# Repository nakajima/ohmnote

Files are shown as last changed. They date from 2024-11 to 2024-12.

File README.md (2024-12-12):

# ohmnote

A little ohmmeter.

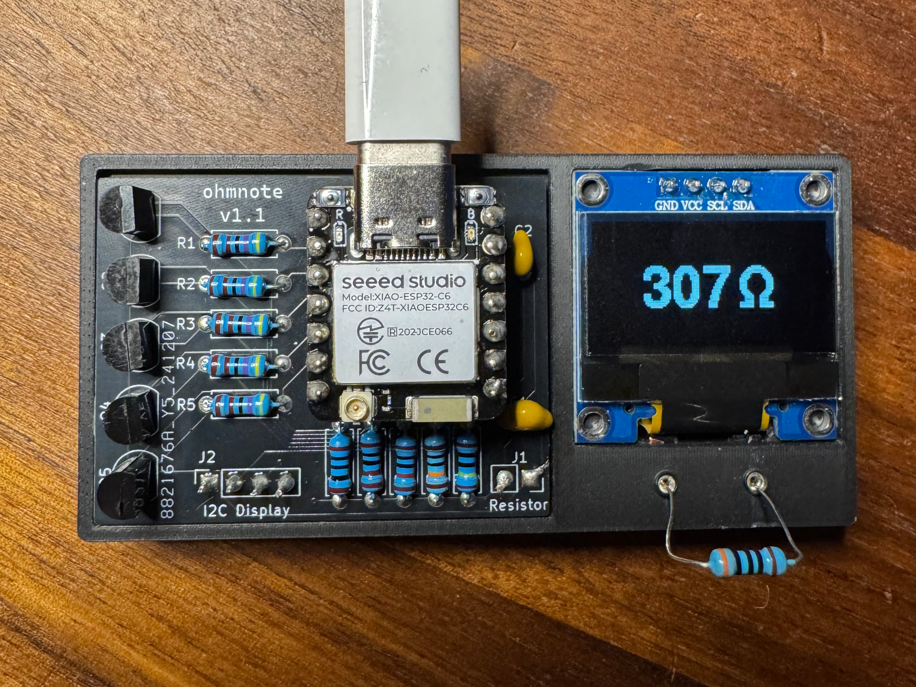
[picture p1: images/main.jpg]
Photo of ohmmeter


I wrote it in rust but it was adapted from: https://simple-circuit.com/arduino-auto-ranging-ohmmeter-lcd and https://www.hackster.io/Costalegre/auto-ranging-ohmmeter-6fa4af.

If you want to make it yourself, you can use the PCB files in the Gerbers/ directory and the 3D model in ohmnote.3mf.

## BOM

- **5** 4.7KΩ resistors
- **1** 1MΩ resistor
- **1** 100KΩ resistor
- **1** 10KΩ resistor
- **1** 1KΩ resistor
- **1** 100Ω resistor
- **5** BJT PNP transistors (i used 2N3906 and don't know enough about transistors to be able to say what else might work)
- **2** 100nf capacitors
- **1** SSD1306 OLED screen (i used [this one](https://www.amazon.com/gp/product/B09T6SJBV5/ref=ppx_yo_dt_b_search_asin_title?ie=UTF8&psc=1))
- **2** Header sockets
- **1** [XIAO ESP32C6](https://www.seeedstudio.com/Seeed-Studio-XIAO-ESP32C6-p-5884.html) (this is what I used because I had one around, it probably wouldn't be too tough to use something else with the same form factor, you'd just have to change some code)
- Some stranded wires
- Some copper tape

## Assembly

### Print out the parts

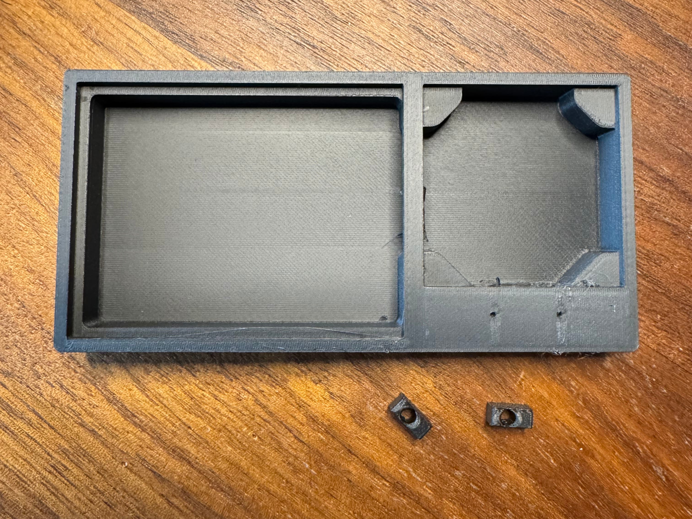
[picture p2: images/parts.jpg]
3D printed parts


### Push the headers into the holes on the main part

I used my soldering iron on the lowest heat setting and they just sank in.

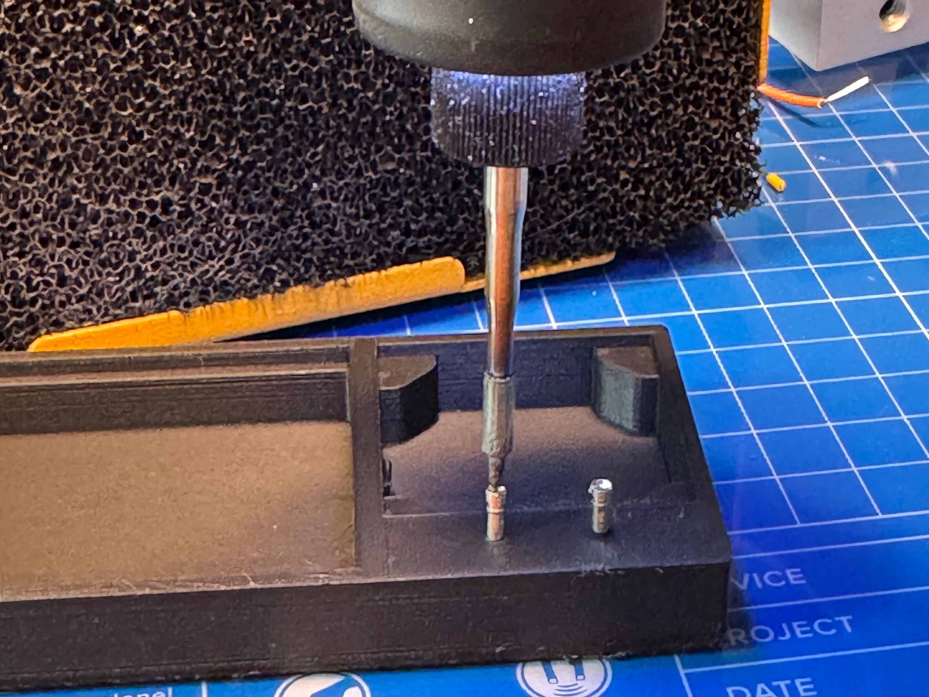
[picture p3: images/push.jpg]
Pushing headers into the body


### Push some wire through the nubbins

These will get pushed into the slots under the headers.

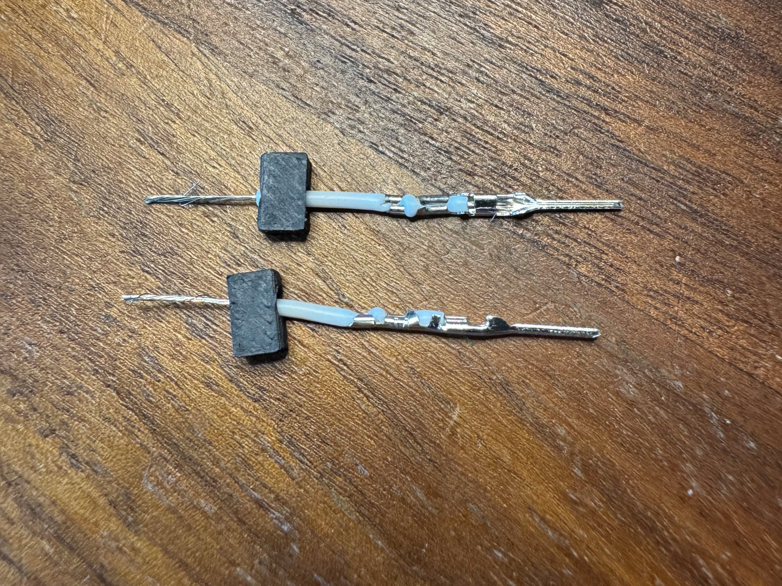
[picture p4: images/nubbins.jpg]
Wire pushed through nubbins


### Secure the loose strands with copper tape

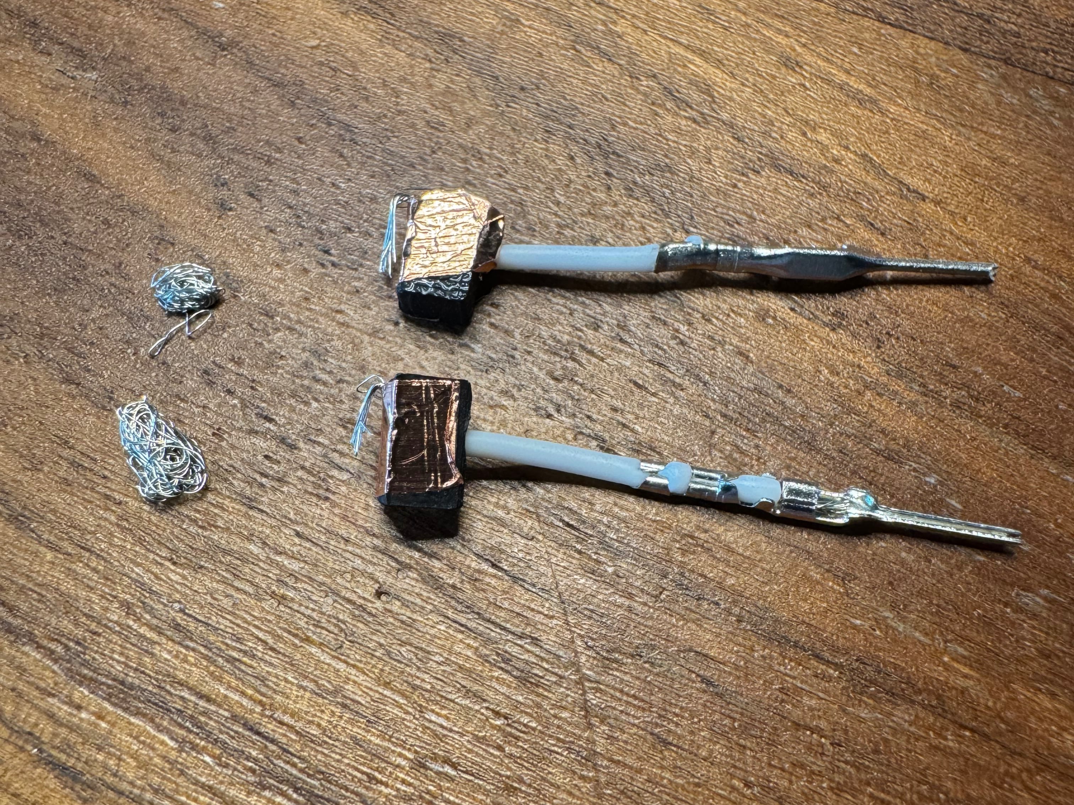
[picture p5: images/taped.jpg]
Wire secured with tape


### Push some other loose strands + the taped nubbins into the body

I also pushed some extra loose strands into the holes to make sure everything was conducting.

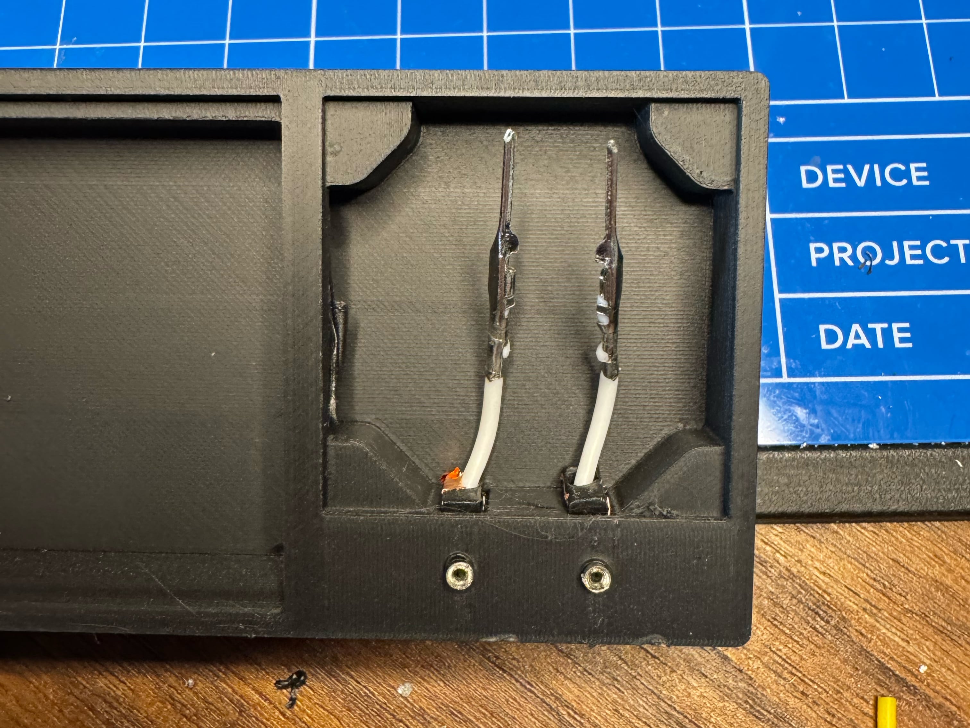
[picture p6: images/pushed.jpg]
Wires pushed into the body


### Get a PCB

I use [JLCPCB](https://jlcpcb.com) personally but you do you!

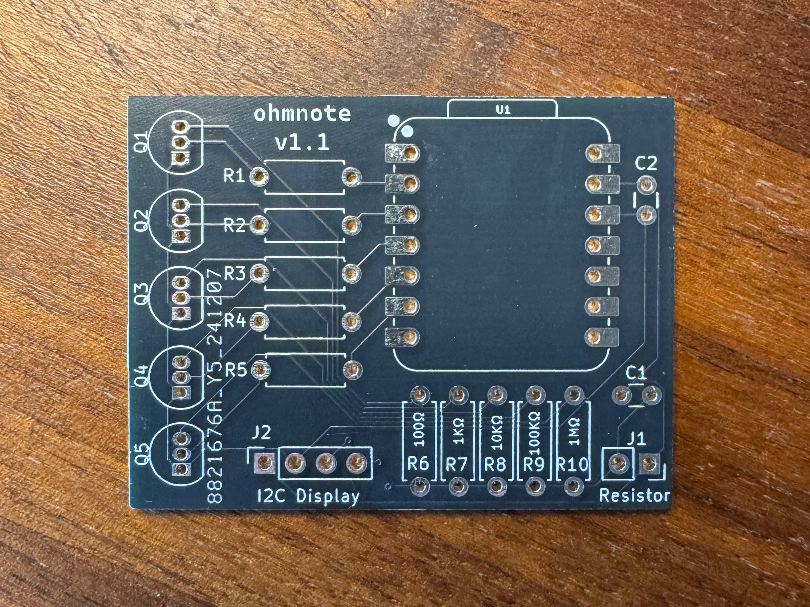
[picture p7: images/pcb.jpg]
PCB


### Solder everything to the pcb

You can use the schematic to see what goes where.

(I didn't take a picture of this but like, you can just look at the other pictures of the board)

### Connect all the wires

I crimped everything so it'd be easier to take apart if I messed something up, but you could just solder all the
wires directly if you want.

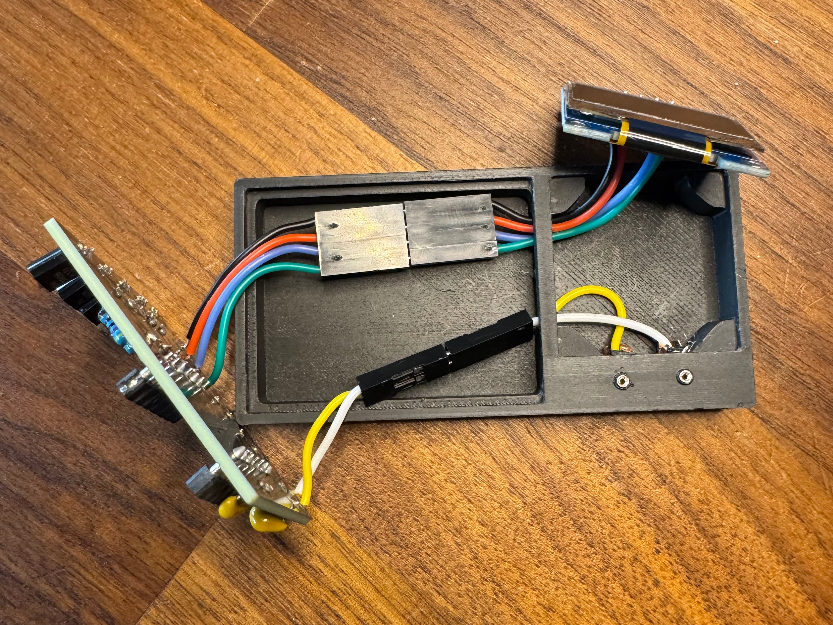
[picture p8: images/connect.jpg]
Connected wires


### Flash the code from this repo to the XIAO board

```sh
$ cargo run --release
```

### You're done!

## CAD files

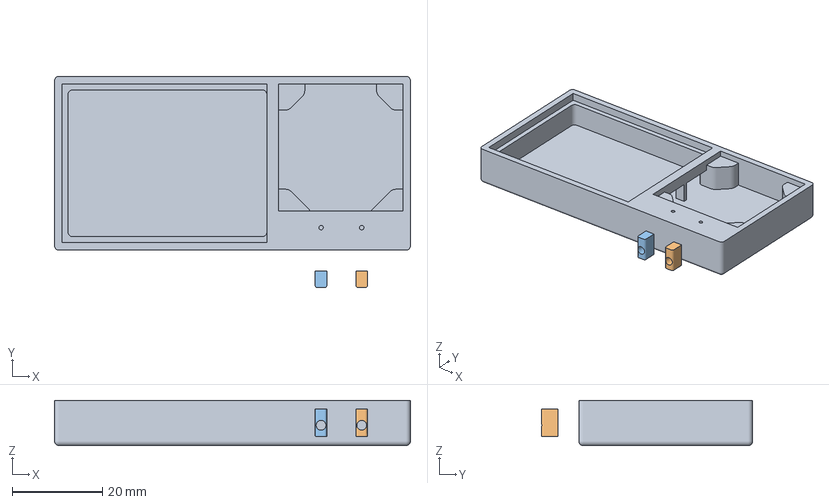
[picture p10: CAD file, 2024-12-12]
ohmnote.3mf
78.8 x 46.8 x 10.0 mm

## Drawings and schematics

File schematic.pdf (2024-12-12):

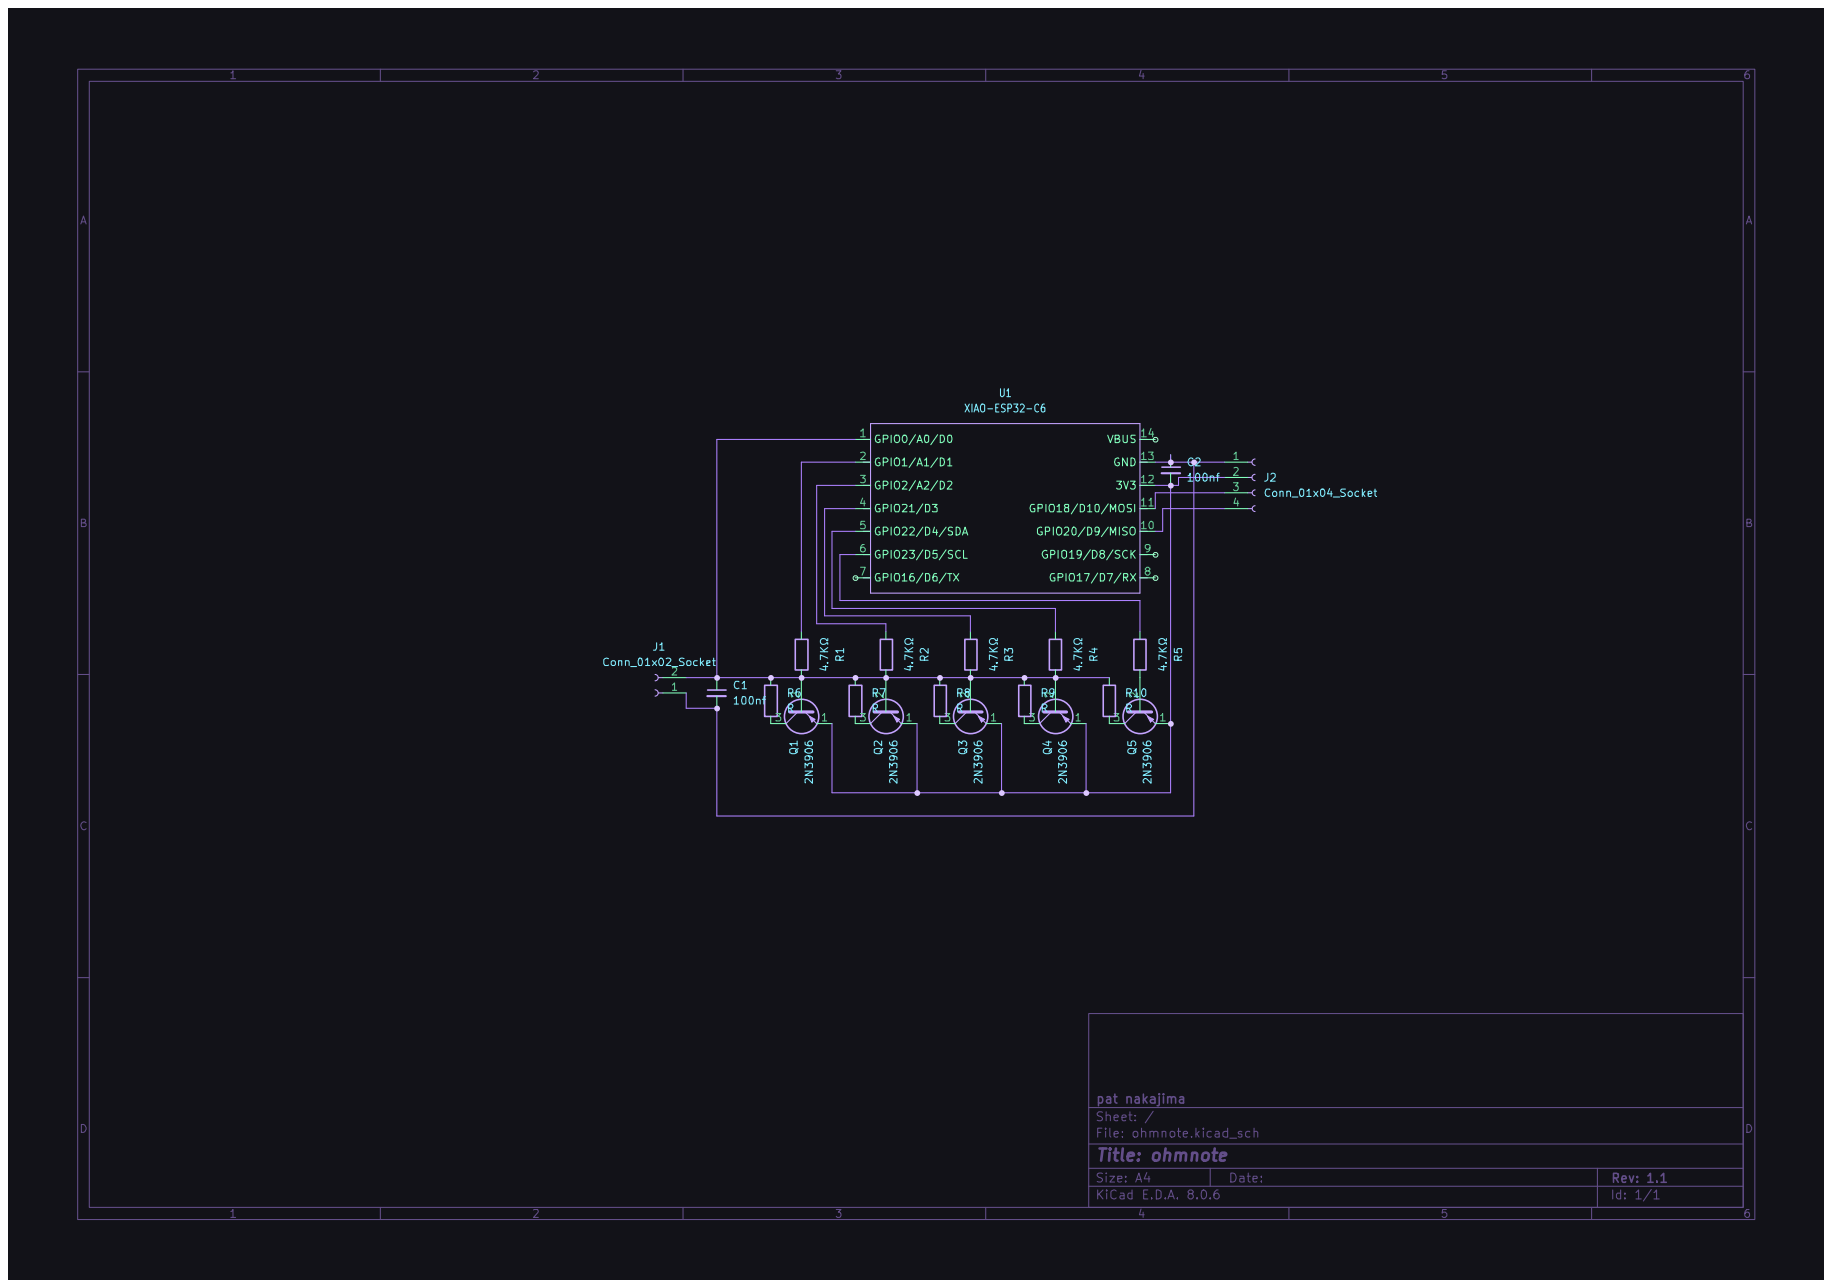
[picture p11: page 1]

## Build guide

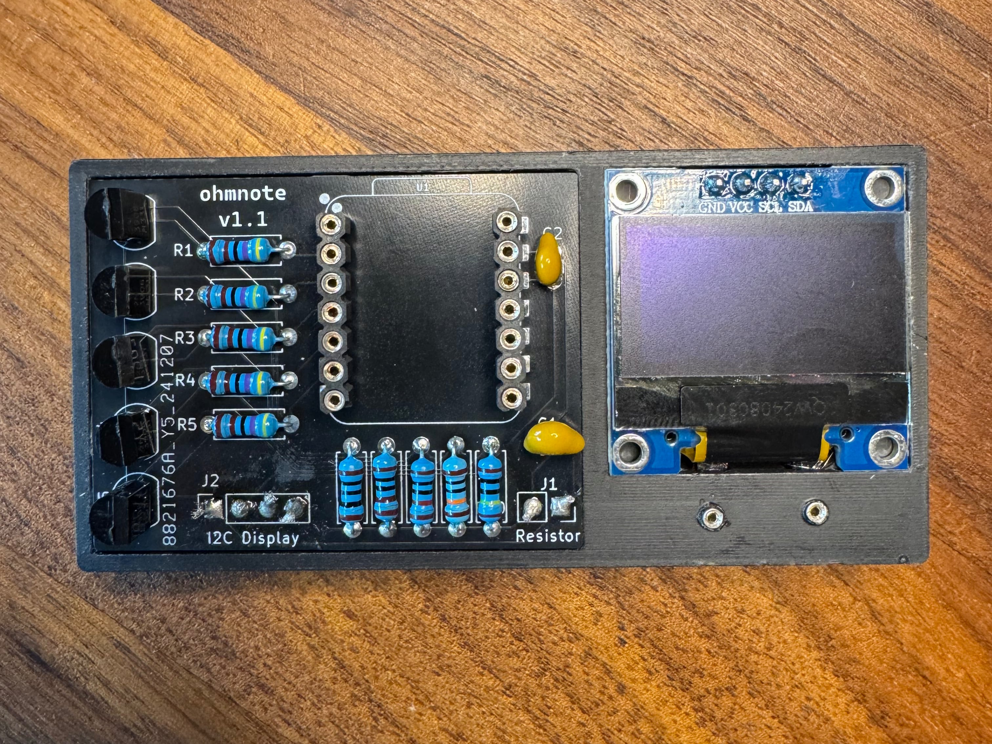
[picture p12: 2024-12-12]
images/assembled.jpg

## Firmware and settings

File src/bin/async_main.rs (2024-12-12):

#![no_std]
#![no_main]
#![feature(impl_trait_in_assoc_type)]

use embassy_executor::Spawner;
use embassy_time::Timer;
use esp_backtrace as _;
use esp_hal::{
    gpio::{Level, Output},
    i2c::{self, master::I2c},
    peripherals::ADC1,
    prelude::*,
};
use esp_println::logger::init_logger;
use ohmnote::{
    display::{init_display, READING},
    meter::Meter,
};

#[main]
async fn main(spawner: Spawner) {
    init_logger(log::LevelFilter::Trace);

    let peripherals = esp_hal::init({
        let mut config = esp_hal::Config::default();
        config.cpu_clock = CpuClock::max();
        config
    });

    let timg0 = esp_hal::timer::timg::TimerGroup::new(peripherals.TIMG0);
    esp_hal_embassy::init(timg0.timer0);
    log::info!("Embassy initialized");

    let scl = peripherals.GPIO18;
    let sda = peripherals.GPIO20;

    let mut config = i2c::master::Config::default();
    config.frequency = 1_000.kHz();
    let i2c = I2c::new(peripherals.I2C0, config)
        .with_scl(scl)
        .with_sda(sda)
        .into_async();

    // Pull pins we're not using low
    Output::new(peripherals.GPIO16, Level::Low);
    Output::new(peripherals.GPIO19, Level::Low);
    Output::new(peripherals.GPIO17, Level::Low);

    // Reset display
    // let mut rst = Output::new(rst, Level::High);
    // rst.set_high();
    // Timer::after_millis(10).await;
    // rst.set_low();
    // Timer::after_millis(10).await;
    // rst.set_high();
    // Timer::after_millis(100).await;

    spawner.spawn(init_display(i2c)).unwrap();

    let range_100_ohm = esp_hal::gpio::Output::new(peripherals.GPIO1, Level::Low);
    let range_1k_ohm = esp_hal::gpio::Output::new(peripherals.GPIO2, Level::Low);
    let range_10k_ohm = esp_hal::gpio::Output::new(peripherals.GPIO21, Level::Low);
    let range_100k_ohm = esp_hal::gpio::Output::new(peripherals.GPIO22, Level::Low);
    #[allow(non_snake_case)]
    let range_1m_ohm = esp_hal::gpio::Output::new(peripherals.GPIO23, Level::Low);

    let mut meter = Meter::new(
        range_100_ohm,
        range_1k_ohm,
        range_10k_ohm,
        range_100k_ohm,
        range_1m_ohm,
    );

    type AdcCal = esp_hal::analog::adc::AdcCalBasic<ADC1>;
    let mut adc_config = esp_hal::analog::adc::AdcConfig::default();
    let mut adc_pin = adc_config.enable_pin_with_cal::<_, AdcCal>(
        peripherals.GPIO0,
        esp_hal::analog::adc::Attenuation::Attenuation11dB,
    );
    let mut adc = esp_hal::analog::adc::Adc::new(peripherals.ADC1, adc_config);

    meter.set_channel(4);

    loop {
        log::info!("reading channel {}", meter.channel);
        let voltage = adc.read_oneshot(&mut adc_pin).unwrap();
        log::info!("voltage: {}", voltage);
        let result = meter.read(voltage).await;

        READING.sender().send(result.clone());

        Timer::after_millis(10).await;
    }
}

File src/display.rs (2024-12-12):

use embassy_executor::task;
use embassy_sync::blocking_mutex::raw::CriticalSectionRawMutex;
use embassy_sync::watch::Watch;
use embassy_time::Timer;
use embedded_graphics::draw_target::DrawTarget;
use embedded_graphics::geometry::Dimensions;
use embedded_graphics::geometry::OriginDimensions;
use embedded_graphics::image::Image;
use embedded_graphics::pixelcolor::BinaryColor;
use embedded_graphics::prelude::Point;
use embedded_graphics::Drawable;
use esp_hal::{i2c::master::I2c, Async};
use heapless::String;
use ssd1306::mode::DisplayConfig;
use ssd1306::{prelude::DisplayRotation, size::DisplaySize128x64, I2CDisplayInterface, Ssd1306};
use tinybmp::Bmp;
use u8g2_fonts::types::FontColor;
use u8g2_fonts::types::VerticalPosition;
use u8g2_fonts::{fonts, FontRenderer};

pub static READING: Watch<CriticalSectionRawMutex, Option<String<32>>, 1> = Watch::new();

#[task]
pub async fn init_display(i2c: I2c<'static, Async>) {
    log::info!("init_display");

    let interface = I2CDisplayInterface::new(i2c);
    let mut display = Ssd1306::new(interface, DisplaySize128x64, DisplayRotation::Rotate0)
        .into_buffered_graphics_mode();

    while display.init().is_err() {
        log::warn!("init_display failed: {:?}, retrying", display.init().err());
        Timer::after_millis(50).await;
    }

    // Include the BMP file data.
    let bmp_data = include_bytes!("../ohm.bmp");

    // Parse the BMP file.
    let bmp: Bmp<BinaryColor> = Bmp::from_slice(bmp_data).unwrap();
    let bmp_size = bmp.size();

    loop {
        let font = FontRenderer::new::<fonts::u8g2_font_helvB24_te>();
        let reading = READING.receiver().unwrap().changed().await;

        // Clear the display buffer
        display.clear(BinaryColor::Off).unwrap();

        if let Some(reading) = reading {
            // Get the dimensions of the rendered text
            let text_dimensions = font
                .get_rendered_dimensions(
                    reading.as_str(),
                    Point::zero(),
                    VerticalPosition::Baseline,
                )
                .unwrap();

            let text_width = text_dimensions.bounding_box.unwrap().size.width as i32;
            let text_height = text_dimensions.bounding_box.unwrap().size.height as i32;

            // Get the dimensions of the ohm symbol
            let symbol_width = bmp_size.width as i32;
            let symbol_height = bmp_size.height as i32;

            // Define space between text and symbol
            let space_between = 5; // Adjust this value as needed

            // Total width of text, space, and symbol
            let total_width = text_width + space_between + symbol_width;

            // Calculate starting X position to center content
            let display_width = display.bounding_box().size.width as i32;
            let starting_x = (display_width - total_width) / 2;

            // Baseline Y position (adjust as needed)
            let baseline_y = (display.bounding_box().size.height as i32 + text_height) / 2;

            // Render the text
            font.render(
                reading.as_str(),
                Point::new(starting_x, baseline_y),
                VerticalPosition::Baseline,
                FontColor::Transparent(BinaryColor::On),
                &mut display,
            )
            .unwrap();

            // Render the ohm symbol next to the text with spacing
            let symbol_x = starting_x + text_width + space_between;
            let symbol_y = baseline_y - symbol_height;

            Image::new(&bmp, Point::new(symbol_x, symbol_y))
                .draw(&mut display)
                .unwrap();
        } else {
            let font = FontRenderer::new::<fonts::u8g2_font_helvB14_te>();
            font.render(
                "ohmnote",
                Point::new(24, display.bounding_box().size.height as i32 / 2 + 10),
                VerticalPosition::Baseline,
                FontColor::Transparent(BinaryColor::On),
                &mut display,
            )
            .unwrap();
        }

        // Flush the display buffer to the screen
        display.flush().unwrap();

        Timer::after_millis(100).await;
    }
}

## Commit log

2024-12-12 cleanup for open sourcing
    [ohmnote-B_Cu.gbr, ohmnote-B_Mask.gbr, ohmnote-B_Paste.gbr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]
2024-12-12 add board
